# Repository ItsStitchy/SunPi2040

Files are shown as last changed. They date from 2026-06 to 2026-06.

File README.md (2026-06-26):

# SunPi2040 ☀️

This is my custom development board powered by the **RP2040** chip. 

Instead of just cheating and throwing a pre-made Raspberry Pi Pico or a Seeed XIAO onto a blank board, I wanted to learn how to route the actual raw microcontroller silicon entirely from scratch. 

It's built for my **Hack Club Macondo** hardware project!

## 🚀 What's on it?
* **RP2040 Microcontroller:**
* **LED** There's one LED that works as a status light
* **16MB Flash Memory:** (Winbond W25Q128) so I have plenty of space to flash scripts.
* **USB-C Port:** For power and data, because Micro-USB belongs in the trash.
* **AMS1117-3.3V:** To drop the USB power down safely so the chip doesn't explode.
* **Pin Headers:** Two rows of 20-pin headers so I can actually plug this into a breadboard.

The PCB was designed using KiCAD, and I went from never even touching hardware design to creating this devboard. Along the way, I struggled with lots of issues like DRC errors and terrible routing where I met a lot of dead ends.
I created this project in order to learn how to work with KiCAD and hardware design, so that I can work on another project which is a game console-style project.
I found PCB easter eggs quite amusing, and so I decided to include a bunch of PCB easter eggs at the back.

Pictures of the Devboard:

Screenshot 2026-06-01 at 12 27 57 AM
Screenshot 2026-06-01 at 12 28 18 AMScreenshot 2026-06-01 at 12 28 43 AM

Open source, feel free to check out my schematics or tell me where my routing looks messy.

Attached are the images of the schematic and the PCB

Screenshot 2026-06-12 at 6 31 29 PM
Screenshot 2026-06-12 at 6 31 08 PM

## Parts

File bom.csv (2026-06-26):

Product Name | Product Link | Total Cost (US) | Amount | Cost With Shipping
JLCPCB PCB and Stencil | https://jlcpcb.com/ | 9.16 | 5 PCBs | 10.83
LCSC Components | https://lcsc.com/ | 30.62 | 1 | 30.62
MHP30 PD65W Mini Hot Plate | https://www.aliexpress.com/item/1005008077648223.html | 12.74 | 1 | 12.74
Pinecil V2 | https://www.aliexpress.com/item/1005012505708387.html | 38.42 | 1 | 38.42
JCD 820 Aluminum Alloy Electric Soldering Iron Stand Holder | https://www.aliexpress.com/item/1005002842145055.html | 4.45 | 1 | 4.45
MECHANIC XG-50 42g Solder Paste | https://www.aliexpress.com/item/4000036983982.html | 3.40 | 1 | 3.40
50g 63/37 Soldering Wire | https://www.aliexpress.com/item/1005001826521446.html | 3.70 | 1 | 3.70
ESD-15 Tweezers | https://www.aliexpress.com/item/32860810385.html | 2.27 | 1 | 2.27
Cutters | https://www.aliexpress.com/item/1005006853321960.html | 1.51 | 1 | 1.51
Total Aliexpress with shipping |  | 66.49 |  | 68.99
Subtotal |  | 110.44

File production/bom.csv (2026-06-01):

Designator | Footprint | Quantity | Value | LCSC Part #
C1, C11, C12, C17, C2, C3, C4, C5, C6, C7, C8, C9 | 0603 | 12 | 0.1uF
C10 | 0603 | 1 | 1uF
C13, C14 | 0603 | 2 | 10uF
C15, C16 | 0603 | 2 | 33pF
D1 | 1206 | 1 | LED
J1 | USB_C_Receptacle_GCT_USB4105-xx-A_16P_TopMnt_Horizontal | 1 | USB_C_Receptacle_USB2.0_14P
J2, J4 | PinHeader_1x20_P2.54mm_Vertical | 2 | Conn_01x20_Pin
J3 | PinHeader_1x03_P2.54mm_Vertical | 1 | Conn_01x03_Pin
R1, R2 | 0603 | 2 | 5.1K
R3, R4 | 0603 | 2 | 27
R5, R6 | 0603 | 2 | 1K
R7 | 0603 | 1 | 10K
R8 | 0603 | 1 | 330
SW1 | SW_Push_SPST_NO_Alps_SKRK | 1 | SW_Push
U1 | QFN-56-1EP_7x7mm_P0.4mm_EP3.2x3.2mm | 1 | RP2040
U2 | SOT-223-3_TabPin2 | 1 | NCP1117-3.3_SOT223
U3 | SOIC-8_5.3x5.3mm_P1.27mm | 1 | W25Q128JVS
Y1 | Crystal_SMD_3225-4Pin_3.2x2.5mm | 1 | 12 MHz

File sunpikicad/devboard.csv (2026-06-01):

Reference | Qty | Value | DNP | Exclude from BOM | Exclude from Board | Footprint | Datasheet
C1,C2,C3,C4,C5,C6,C7,C8,C9,C11,C12,C17 | 12 | 0.1uF |  |  |  | Capacitor_SMD:C_0603_1608Metric
C10 | 1 | 1uF |  |  |  | Capacitor_SMD:C_0603_1608Metric
C13,C14 | 2 | 10uF |  |  |  | Capacitor_SMD:C_0603_1608Metric
C15,C16 | 2 | 33pF |  |  |  | Capacitor_SMD:C_0603_1608Metric
D1 | 1 | LED |  |  |  | LED_SMD:LED_1206_3216Metric_ReverseMount_Hole1.8x2.4mm
J1 | 1 | USB_C_Receptacle_USB2.0_14P |  |  |  | Connector_USB:USB_C_Receptacle_GCT_USB4105-xx-A_16P_TopMnt_Horizontal | https://www.usb.org/sites/default/files/documents/usb_type-c.zip
J2,J4 | 2 | Conn_01x20_Pin |  |  |  | Connector_PinHeader_2.54mm:PinHeader_1x20_P2.54mm_Vertical
J3 | 1 | Conn_01x03_Pin |  |  |  | Connector_PinHeader_2.54mm:PinHeader_1x03_P2.54mm_Vertical
R1,R2 | 2 | 5.1K |  |  |  | Resistor_SMD:R_0603_1608Metric
R3,R4 | 2 | 27 |  |  |  | Resistor_SMD:R_0603_1608Metric
R5,R6 | 2 | 1K |  |  |  | Resistor_SMD:R_0603_1608Metric
R7 | 1 | 10K |  |  |  | Resistor_SMD:R_0603_1608Metric
R8 | 1 | 330 |  |  |  | Resistor_SMD:R_0603_1608Metric
SW1 | 1 | SW_Push |  |  |  | Button_Switch_SMD:SW_Push_SPST_NO_Alps_SKRK
U1 | 1 | RP2040 |  |  |  | Package_DFN_QFN:QFN-56-1EP_7x7mm_P0.4mm_EP3.2x3.2mm | https://datasheets.raspberrypi.com/rp2040/rp2040-datasheet.pdf
U2 | 1 | NCP1117-3.3_SOT223 |  |  |  | Package_TO_SOT_SMD:SOT-223-3_TabPin2 | http://www.onsemi.com/pub_link/Collateral/NCP1117-D.PDF
U3 | 1 | W25Q128JVS |  |  |  | Package_SO:SOIC-8_5.3x5.3mm_P1.27mm | https://www.winbond.com/resource-files/w25q128jv_dtr%20revc%2003272018%20plus.pdf
Y1 | 1 | 12 MHz |  |  |  | Crystal:Crystal_SMD_3225-4Pin_3.2x2.5mm

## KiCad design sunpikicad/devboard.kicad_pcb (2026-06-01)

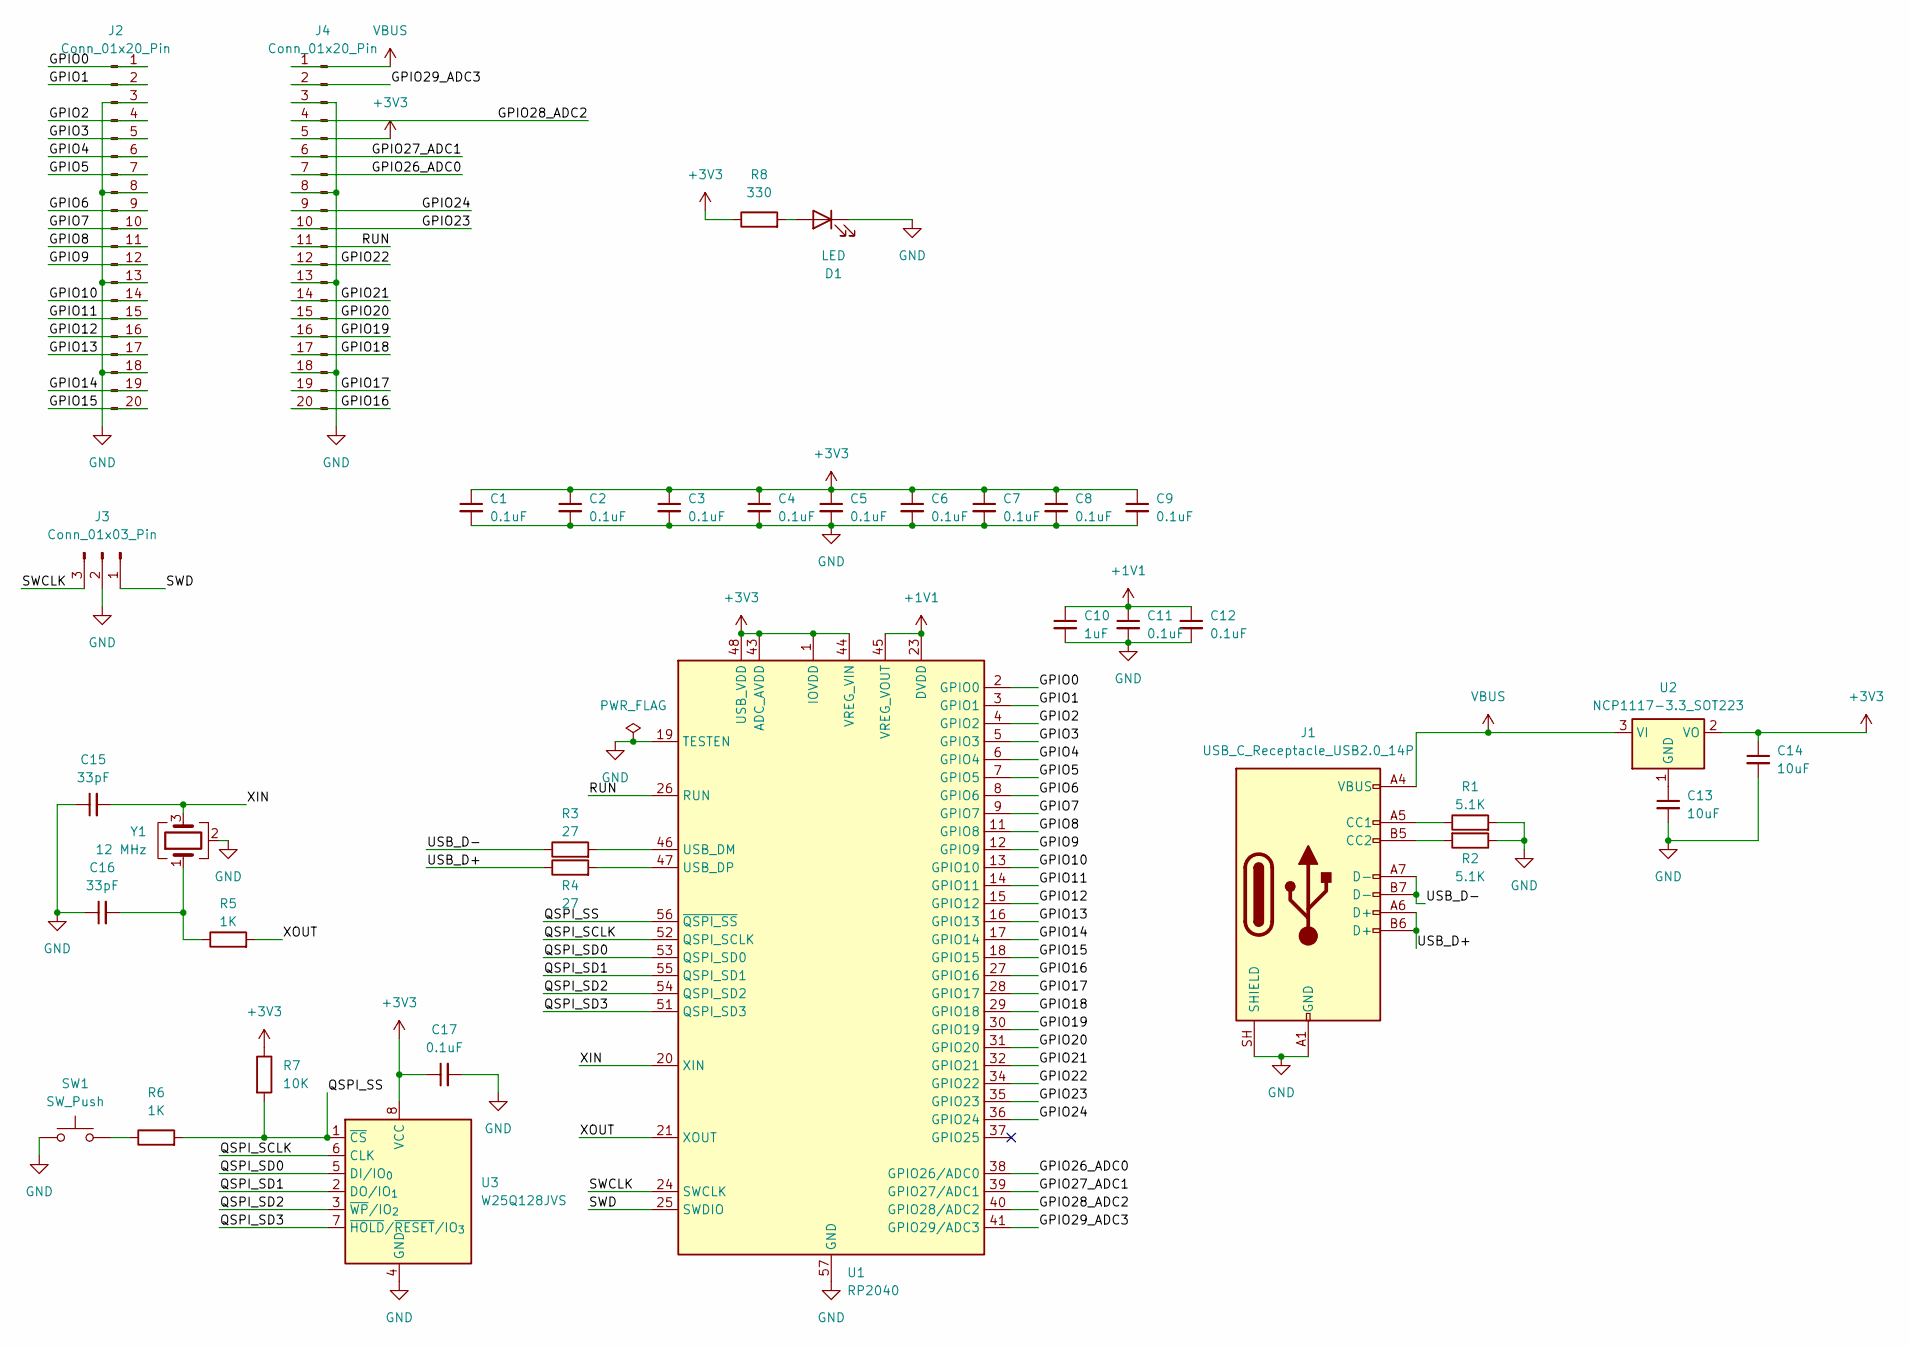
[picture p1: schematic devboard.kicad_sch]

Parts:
C1, C2, C3, C4, C5, C6, C7, C8, C9, C11, C12, C17: 0.1uF; C_0603_1608Metric
C10: 1uF; C_0603_1608Metric
C13, C14: 10uF; C_0603_1608Metric
C15, C16: 33pF; C_0603_1608Metric
D1: LED; LED_1206_3216Metric_ReverseMount_Hole1.8x2.4mm
J1: USB_C_Receptacle_USB2.0_14P; USB_C_Receptacle_GCT_USB4105-xx-A_16P_TopMnt_Horizontal
J2, J4: Conn_01x20_Pin; PinHeader_1x20_P2.54mm_Vertical
J3: Conn_01x03_Pin; PinHeader_1x03_P2.54mm_Vertical
R1, R2: 5.1K; R_0603_1608Metric
R3, R4: 27; R_0603_1608Metric
R5, R6: 1K; R_0603_1608Metric
R7: 10K; R_0603_1608Metric
R8: 330; R_0603_1608Metric
SW1: SW_Push; SW_Push_SPST_NO_Alps_SKRK
U1: RP2040; QFN-56-1EP_7x7mm_P0.4mm_EP3.2x3.2mm
U2: NCP1117-3.3_SOT223; SOT-223-3_TabPin2
U3: W25Q128JVS; SOIC-8_5.3x5.3mm_P1.27mm
Y1: 12 MHz; Crystal_SMD_3225-4Pin_3.2x2.5mm

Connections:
+1V1: C10.1, C11.1, C12.1, U1.23 (DVDD), U1.45 (VREG_VOUT), U1.50 (DVDD)
+3V3: C1.1, C2.1, C3.1, C4.1, C5.1, C6.1, C7.1, C8.1, C9.1, C14.1, C17.1, J4.5, R7.1, R8.1, U1.1 (IOVDD), U1.10 (IOVDD), U1.22 (IOVDD), U1.33 (IOVDD), U1.42 (IOVDD), U1.43 (ADC_AVDD), U1.44 (VREG_VIN), U1.48 (USB_VDD), U1.49 (IOVDD), U2.2 (VO), U3.8 (VCC)
/GPIO0: J2.1, U1.2 (GPIO0)
/GPIO1: J2.2, U1.3 (GPIO1)
/GPIO2: J2.4, U1.4 (GPIO2)
/GPIO3: J2.5, U1.5 (GPIO3)
/GPIO4: J2.6, U1.6 (GPIO4)
/GPIO5: J2.7, U1.7 (GPIO5)
/GPIO6: J2.9, U1.8 (GPIO6)
/GPIO7: J2.10, U1.9 (GPIO7)
/GPIO8: J2.11, U1.11 (GPIO8)
/GPIO9: J2.12, U1.12 (GPIO9)
/GPIO10: J2.14, U1.13 (GPIO10)
/GPIO11: J2.15, U1.14 (GPIO11)
/GPIO12: J2.16, U1.15 (GPIO12)
/GPIO13: J2.17, U1.16 (GPIO13)
/GPIO14: J2.19, U1.17 (GPIO14)
/GPIO15: J2.20, U1.18 (GPIO15)
/GPIO16: J4.20, U1.27 (GPIO16)
/GPIO17: J4.19, U1.28 (GPIO17)
/GPIO18: J4.17, U1.29 (GPIO18)
/GPIO19: J4.16, U1.30 (GPIO19)
/GPIO20: J4.15, U1.31 (GPIO20)
/GPIO21: J4.14, U1.32 (GPIO21)
/GPIO22: J4.12, U1.34 (GPIO22)
/GPIO23: J4.10, U1.35 (GPIO23)
/GPIO24: J4.9, U1.36 (GPIO24)
/GPIO26_ADC0: J4.7, U1.38 (GPIO26/ADC0)
/GPIO27_ADC1: J4.6, U1.39 (GPIO27/ADC1)
/GPIO28_ADC2: J4.4, U1.40 (GPIO28/ADC2)
/GPIO29_ADC3: J4.2, U1.41 (GPIO29/ADC3)
/QSPI_SCLK: U1.52 (QSPI_SCLK), U3.6 (CLK)
/QSPI_SD0: U1.53 (QSPI_SD0), U3.5 (DI/IO_{0})
/QSPI_SD1: U1.55 (QSPI_SD1), U3.2 (DO/IO_{1})
/QSPI_SD2: U1.54 (QSPI_SD2), U3.3 (~WP/IO_{2})
/QSPI_SD3: U1.51 (QSPI_SD3), U3.7 (~HOLD/~RESET/IO_{3})
/QSPI_SS: R6.2, R7.2, U1.56 (~QSPI_SS), U3.1 (~CS)
/RUN: J4.11, U1.26 (RUN)
/SWCLK: J3.3, U1.24 (SWCLK)
/SWD: J3.1, U1.25 (SWDIO)
/USB_D+: J1.A6 (D+), J1.B6 (D+), R4.1
/USB_D-: J1.A7 (D-), J1.B7 (D-), R3.1
/XIN: C15.2, U1.20 (XIN), Y1.3
/XOUT: R5.2, U1.21 (XOUT)
GND: C1.2, C2.2, C3.2, C4.2, C5.2, C6.2, C7.2, C8.2, C9.2, C10.2, C11.2, C12.2, C13.2, C14.2, C15.1, C16.1, C17.2, D1.1 (K), J1.A1 (GND), J1.A12 (GND), J1.B1 (GND), J1.B12 (GND), J1.SH (SHIELD), J2.3, J2.8, J2.13, J2.18, J3.2, J4.3, J4.8, J4.13, J4.18, R1.2, R2.1, SW1.1, U1.19 (TESTEN), U1.57 (GND), U3.4 (GND), Y1.2 (G), Y1.4 (G)
unnamed: C16.2, R5.1, Y1.1
unnamed: D1.2 (A), R8.2
unnamed: J1.A5 (CC1), R1.1
unnamed: J1.B5 (CC2), R2.2
unnamed: R6.1, SW1.2
unnamed: R3.2, U1.46 (USB_DM)
unnamed: R4.2, U1.47 (USB_DP)
unnamed: C13.1, U2.1 (GND)
VBUS: J1.A4 (VBUS), J1.A9 (VBUS), J1.B4 (VBUS), J1.B9 (VBUS), J4.1, U2.3 (VI)

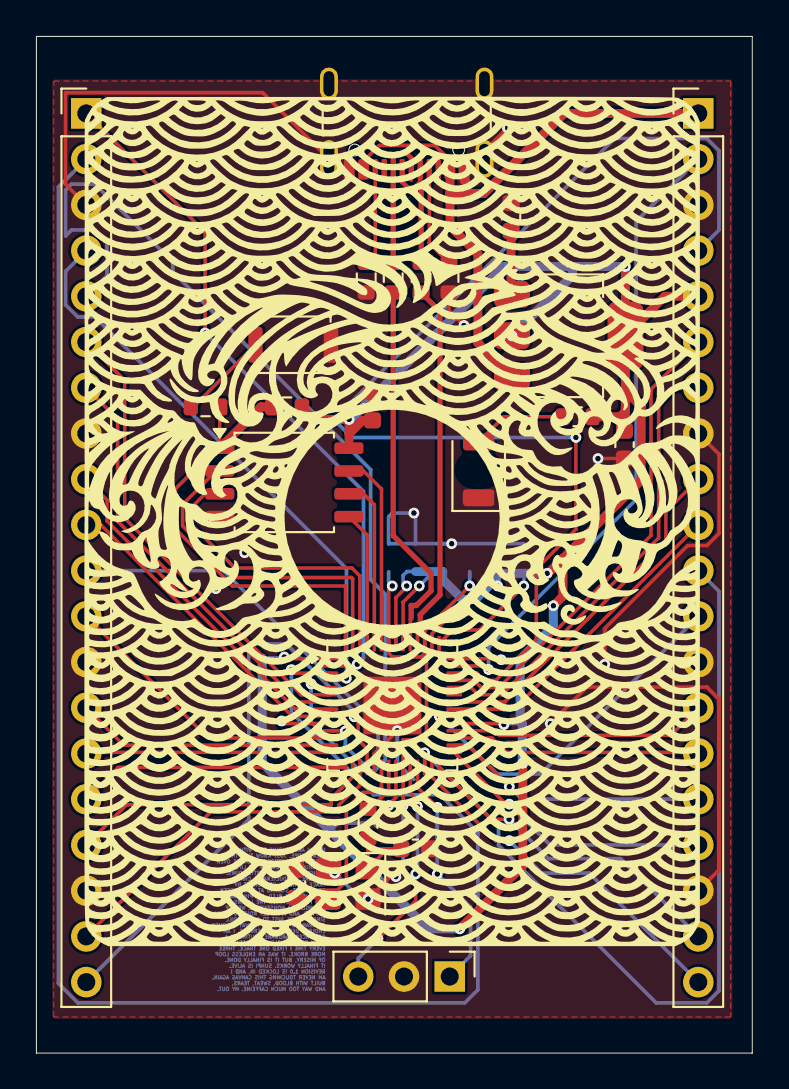
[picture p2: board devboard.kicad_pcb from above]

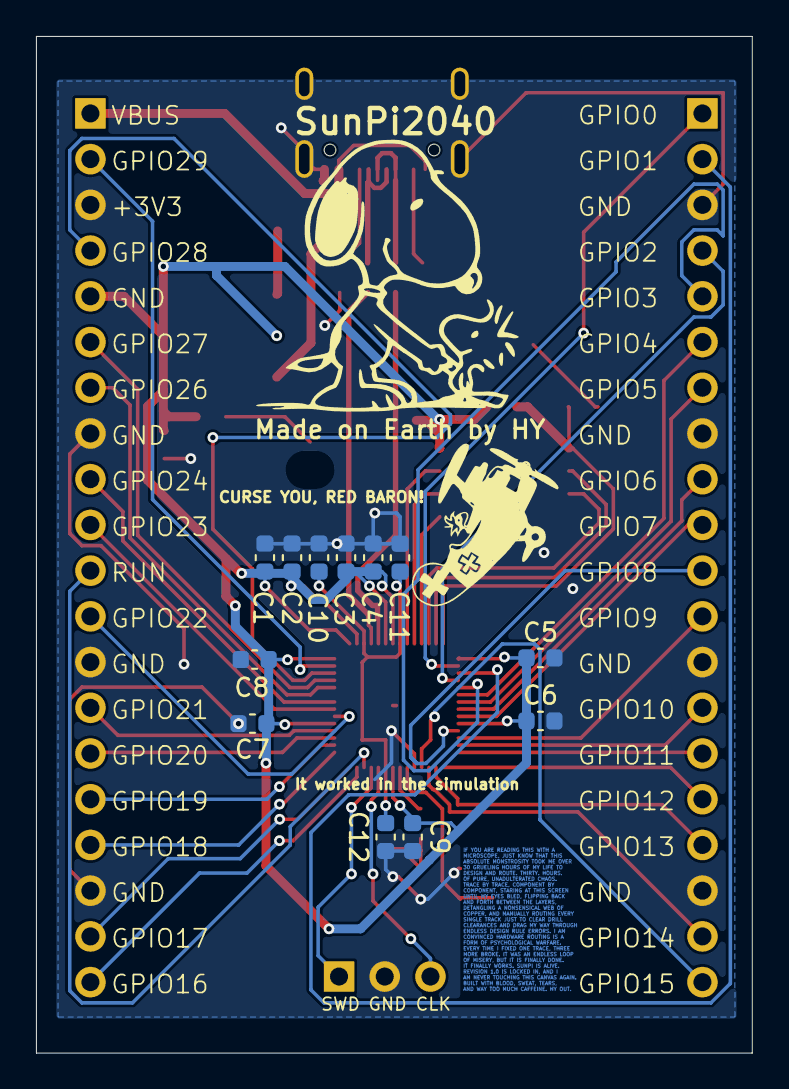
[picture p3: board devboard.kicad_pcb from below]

Board: 2 copper layers, 39.8 x 56.5 mm, 35 parts (12 on the bottom side), 54 nets.

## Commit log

2026-06-01 Production Files uploaded
    these are the production files I used to upload on JLCPCB
    [bom.csv, designators.csv, positions.csv]
2026-06-01 KiCAD files
    [devboard.csv, devboard.kicad_sch]
2026-06-01 Uploaded schematic and pcb diagrams, footprints
    [devboard.csv, devboard.kicad_pcb]
2026-06-26 Modify BOM with new product entries
    Updated product details and added LCSC components.
    [bom.csv]
2026-06-26 Update LCSC Components entry in bom.csv
    Removed the amount for LCSC Components in bom.csv.
    [bom.csv]
2026-06-26 Modify BOM with new product entries and costs
    Updated product details and costs in the BOM.
    [bom.csv]
